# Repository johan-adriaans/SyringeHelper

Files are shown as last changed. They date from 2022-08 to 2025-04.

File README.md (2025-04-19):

# SyringeHelper
A 3D printable tool for repeatable precise dosing of insulin.

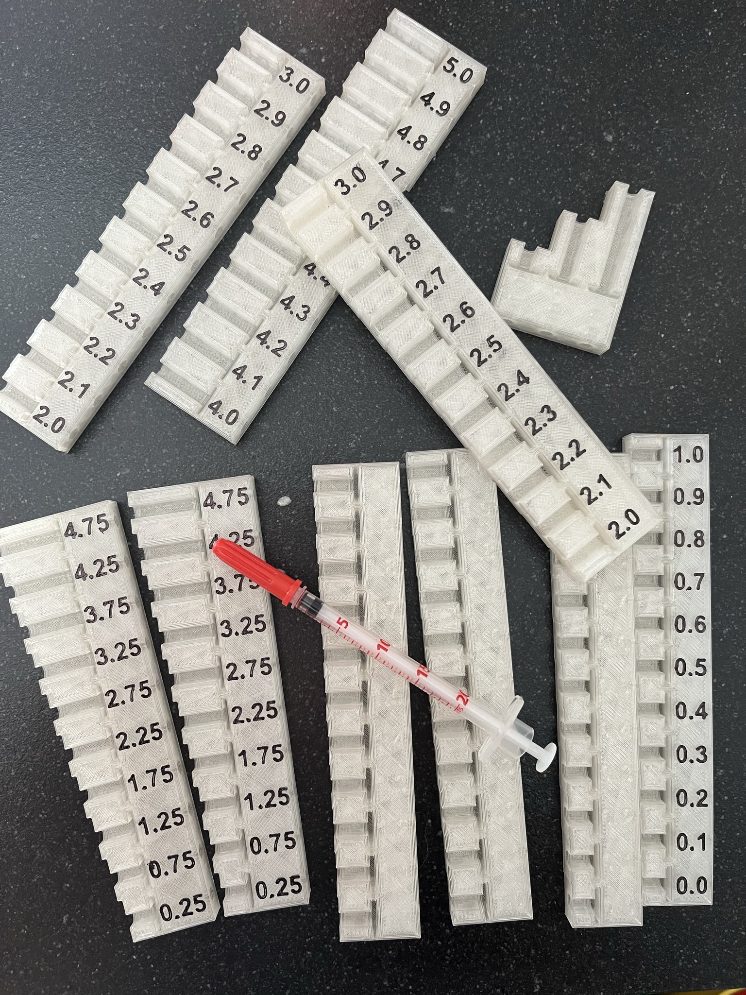
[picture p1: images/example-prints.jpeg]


Also published on:
- https://www.printables.com/model/253310-syringe-dosage-helper
- https://www.thingiverse.com/thing:5448298

## What is it
This is a tool that you fit around the syringe plunger head to get a precise dosage of insulin.

## Currently supported syringes
- BD Micro-Fine+ 0,5ml U40 8mm - EAN: [0382904876036](https://duckduckgo.com/?q=0382904876036)
- BD Micro-Fine+ Demi 0,3ml U100 8mm 30G - EAN: [0382904826031](https://duckduckgo.com/?q=0382904826031)
- BD Ultra-Fine 0,3ml U100 12,7mm 29G - EAN: [0382903261031](https://duckduckgo.com/?q=0382903261031) (Added by [Tony B](https://github.com/tony-butchart))
- Braun Omnican 20 0,5ml U40 8mm - EAN: [4039239541936](https://duckduckgo.com/?q=4039239541936)
- Sol-Vet U100 0,3ml 30G x 1/2" (0.3mm x 12,5mm) - GTIN: [0818392013016](https://www.gs1.org/services/verified-by-gs1/results?gtin=0818392013016)
- Sol-Vet U40 0,3ml 30G x 1/2" (0.3mm x 12,5mm) - REF: V3305-40 GTIN: [818392012682](https://www.gs1.org/services/verified-by-gs1/results?gtin=818392012682)
- Insumed U100 0,3ml 31G x 8mm - Rev. 01/2019 REF: 02 022725 030 150 - EAN: [08058090005322](https://duckduckgo.com/?q=Insumed+08058090005322)

A syringe type is nothing more than a set of values in an OpenSCAD include. It is very doable to add a new type. The code should speak for itself, but feel free to contact me if you have questions.

Note that the U-100 version currently centers on the top part of the plunger. This is a design choice made by https://www.diabetes-katzen.net in their excellent [paper version](https://www.diabetes-katzen.net/images/insulinspritzenmass/Insulinspritzenmass_mit_Erkl%c3%a4rung.pdf). Because we were initially using that, we kept the 0,1 unit offset.

## How to use
- First fill your syringe with a larger amount of insulin.
- Make sure all the bubbles are out.
- Fit the tool around the plunger head.
- Push the tool against the syringe body.
- Validate your result. If your result is different, check if the printed index has an offset. You can see this at the 0 point.

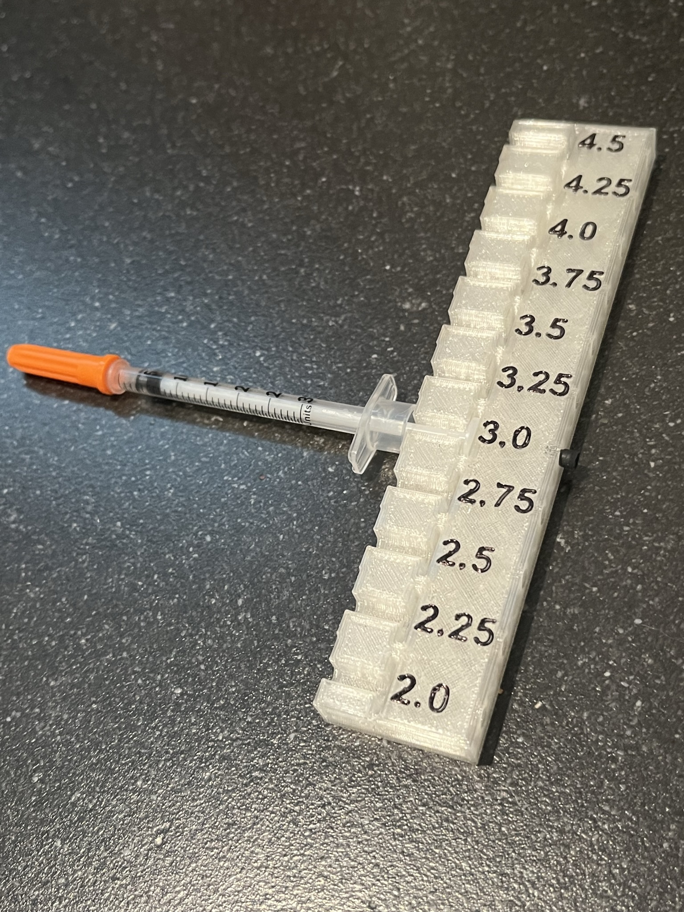
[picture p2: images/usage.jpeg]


Extra: The model has holes on the side where you can fit the rubber head of the plunger. Use this to mark your current dosage.

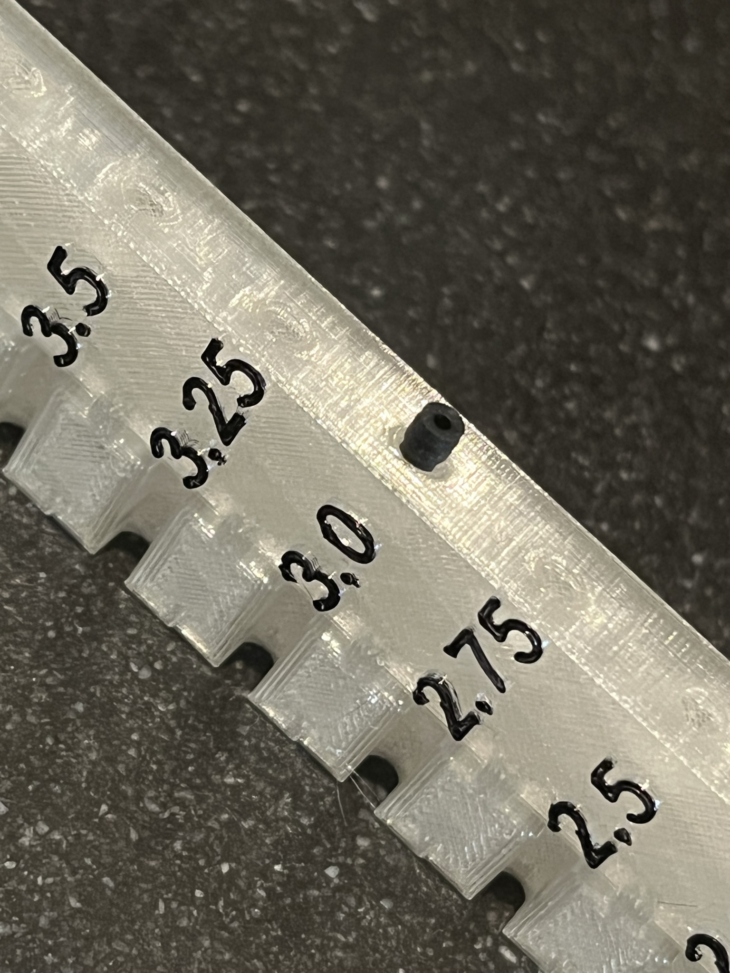
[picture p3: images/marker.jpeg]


## Create your own
You can download these files and open the SyringeHelper.scad file in OpenScad (you need the includes folder too). [OpenScad](https://openscad.org/) is free software that allows you to make a 3D model by programming. It might be a bit daunting to start with, but if you use a supported syringe, it boils down to changing 3 or 4 variables.

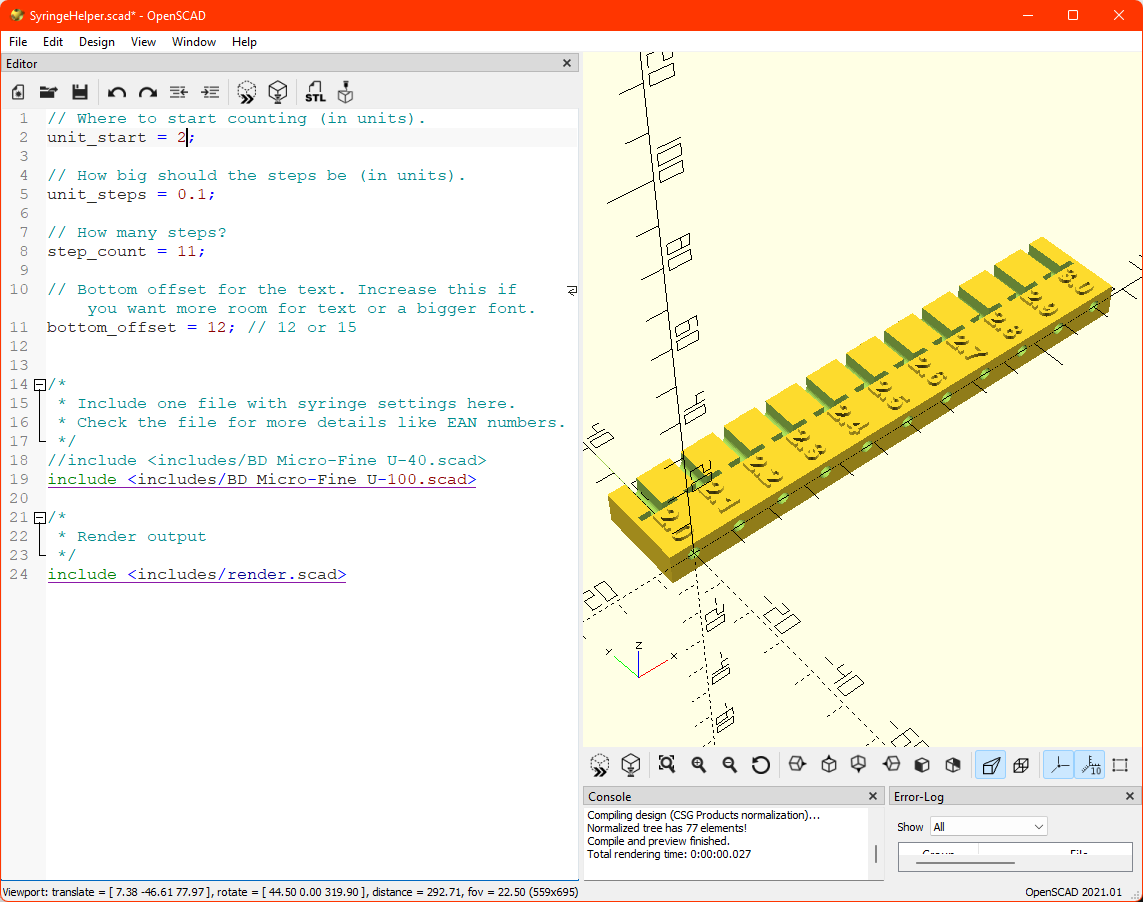
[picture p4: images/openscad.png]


## How did you calibrate?
We started by just measuring the index size of a full syringe. So for a syringe for 30 units of insulin, we would measure the distance between 0 and 30 units in millimeters and use that to calculate a ratio. After that we did some test prints with 3 steps of 10 units to fine-tune this ratio. We went a bit overboard and bought a precision balance ([Kern pcb 250-3](https://www.kern-sohn.com/cgi-bin/cosmoshop/lshop.cgi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)) to measure our results. This scale can repeatably measure down to 1 microgram, so we filled our syringes with water and we were able to ensure our results were correct and repeatable. We discovered the plastic part of the syringe is dependable enough to use as a measurement support. Luckily only the printed index is imprecise.

## Disclaimer
Please test your print before using. This was all calibrated for my 3D Printer (Creality Ender 3 V2). Do not assume my measurements are correct for your syringes. Test them on at least 10 syringes and decide for yourself if you feel comfortable using them.

## Background
We have a cat that needs insulin. A cat is a lot smaller than a human and needs more precise dosing. The pens we found would only be configurable for half a unit of insulin, while an animal as small as a cat could need changes down to 0.1 units. We also found that most manual syringes have a reasonably dependable plastic mold, but imprecise printing. The printed index on the syringe could differ up to 0.2 units. Long story short, it is impossible to measure a repeatable, precise dose without some sort of tool.. So we made a tool.

PS: If you have a diabetic cat and you speak Dutch, feel free to join the forum [Diabeteskatten.nl](https://www.diabeteskatten.nl) for expert advice and support.

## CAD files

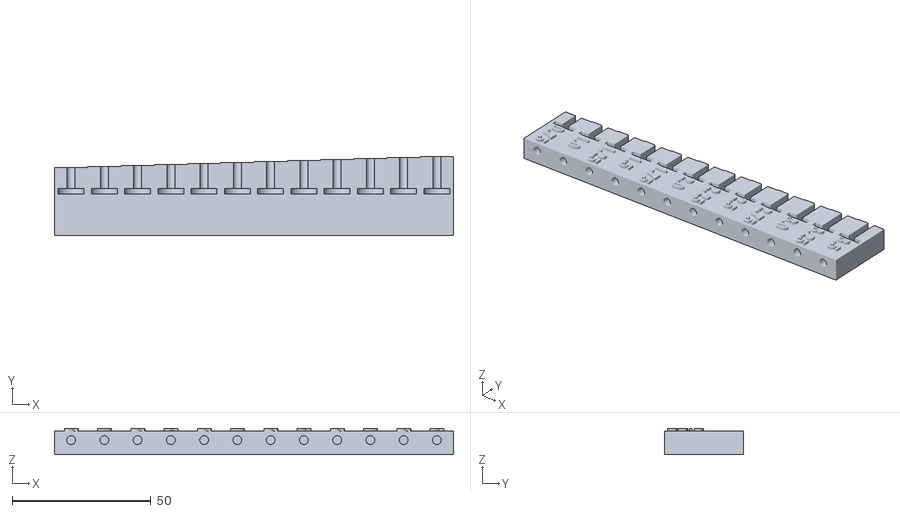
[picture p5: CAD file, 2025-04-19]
stl-examples/Insumed-U100-0.75-to-3.5.stl
144.0 x 28.4 x 9.40

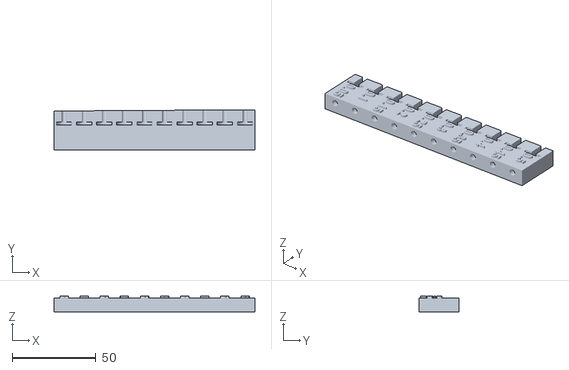
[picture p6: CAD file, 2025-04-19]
stl-examples/Insumed-U100-0.05-to-0.5.stl
120.0 x 24.1 x 9.40

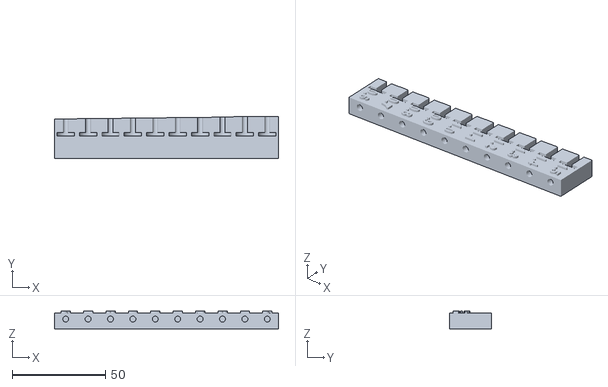
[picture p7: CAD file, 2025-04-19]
stl-examples/Insumed-U100-0.6-to-1.5.stl
120.0 x 22.6 x 9.40

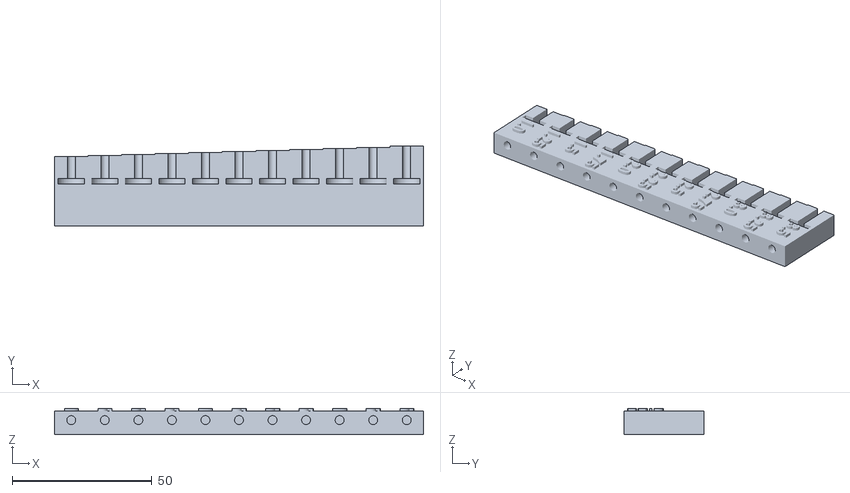
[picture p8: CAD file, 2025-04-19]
stl-examples/Insumed-U100-1-to-3.5.stl
132.0 x 28.4 x 9.40

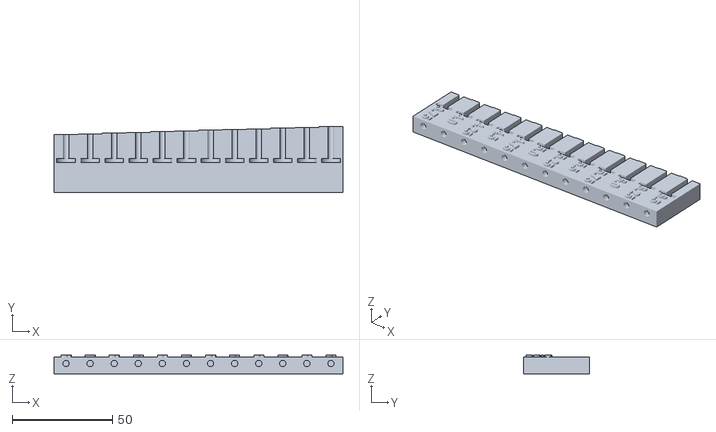
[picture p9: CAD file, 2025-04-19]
stl-examples/Insumed-U100-3.75-to-6.5.stl
144.0 x 32.8 x 9.40

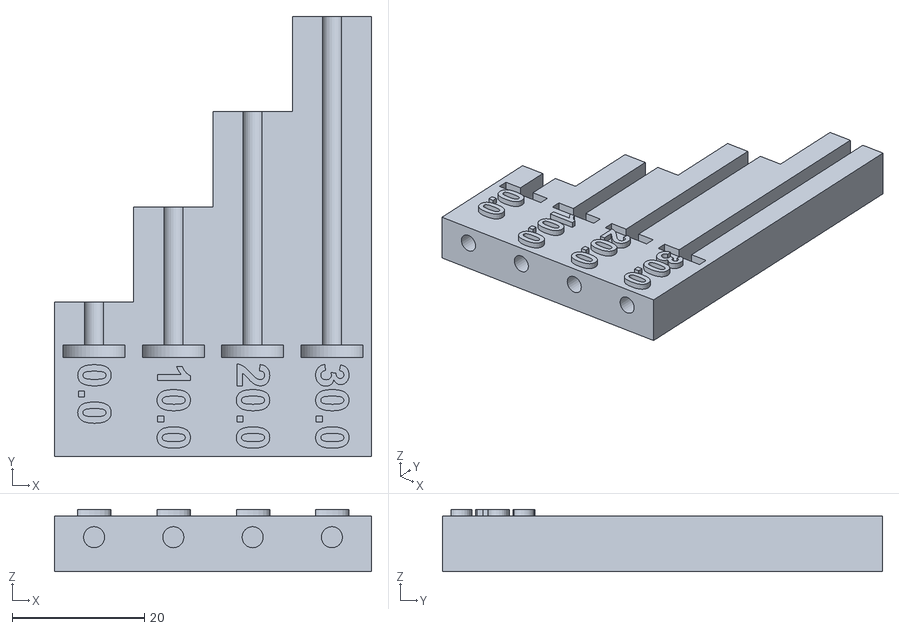
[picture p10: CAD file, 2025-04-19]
stl-examples/Insumed-U100-calibration.stl
48.0 x 66.6 x 9.40

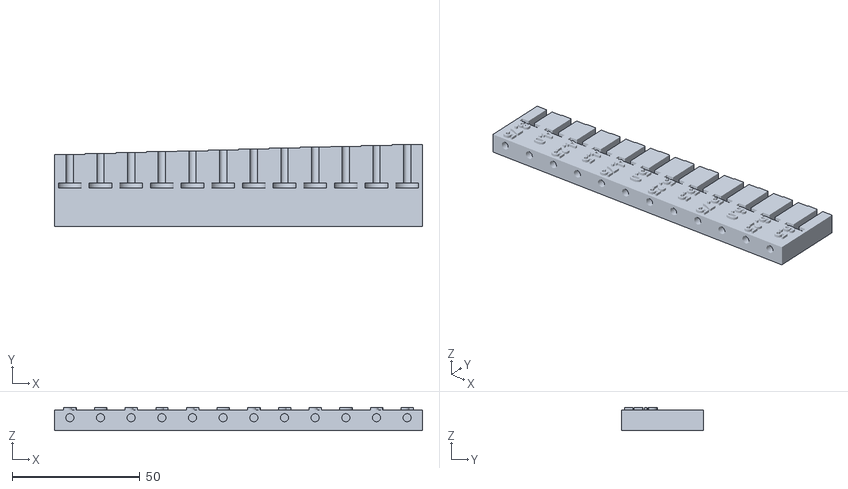
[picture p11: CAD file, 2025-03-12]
stl-examples/SolVet-U100-3.75-to-6.5.stl.stl
144.0 x 32.0 x 9.00

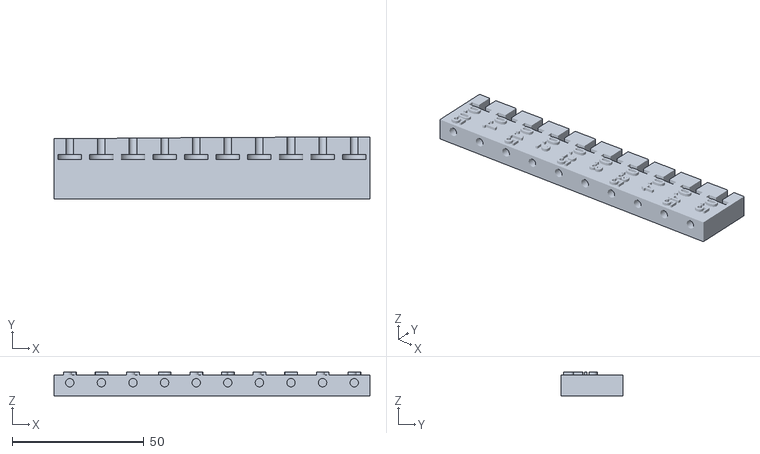
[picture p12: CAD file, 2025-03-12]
stl-examples/SolVet-U100-0.05-to-0.5.stl
120.0 x 23.7 x 9.00

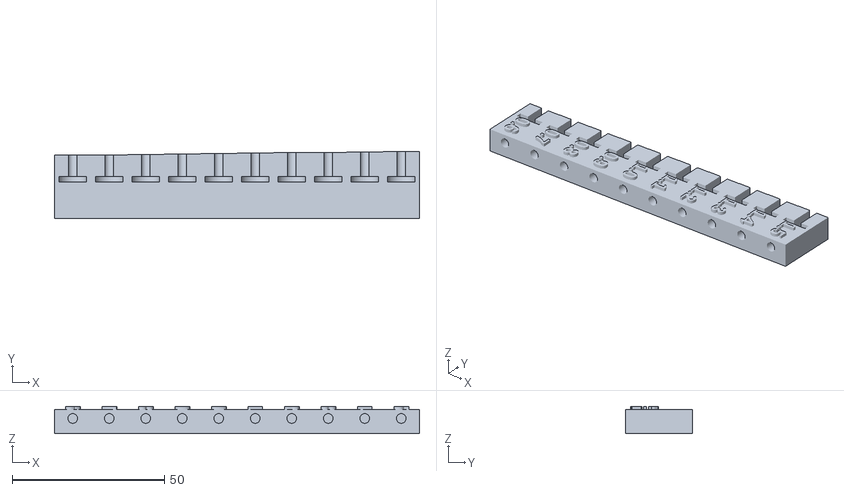
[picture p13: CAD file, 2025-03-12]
stl-examples/SolVet-U100-0.6-to-1.5.stl.stl
120.0 x 22.1 x 9.00

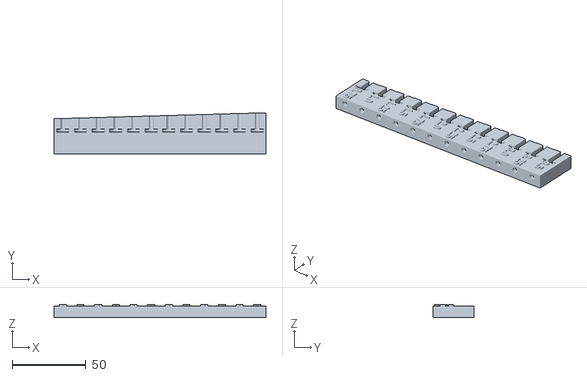
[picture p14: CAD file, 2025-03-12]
stl-examples/SolVet-U100-0.75-to-3.5.stl.stl
144.0 x 27.9 x 9.00

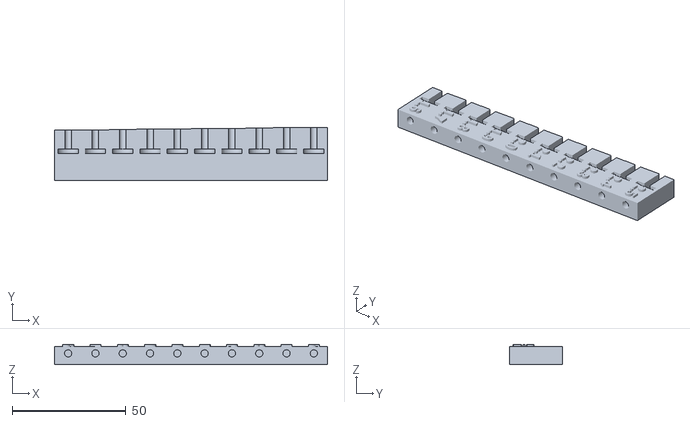
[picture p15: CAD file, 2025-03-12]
stl-examples/SolVet-U100-1.6-to-2.5.stl.stl
120.0 x 23.5 x 9.00

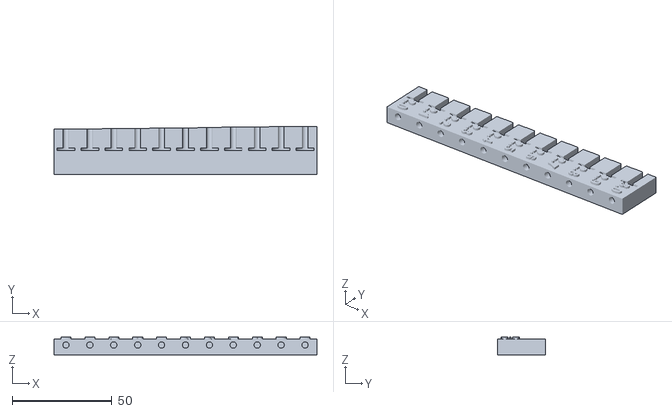
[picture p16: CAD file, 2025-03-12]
stl-examples/BDUltraFine-U100-2-to-3.stl
132.0 x 24.2 x 9.00

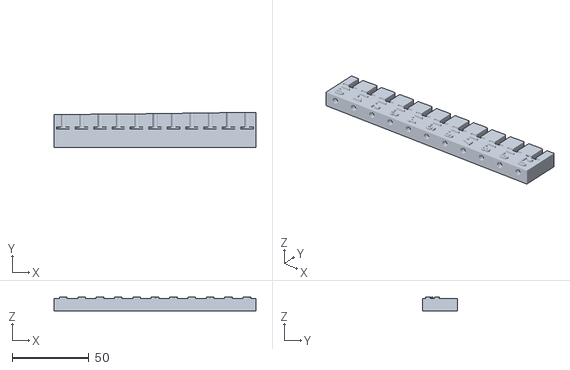
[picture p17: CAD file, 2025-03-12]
stl-examples/BDUltraFine-U100-1-to-2.stl
132.0 x 22.8 x 9.00

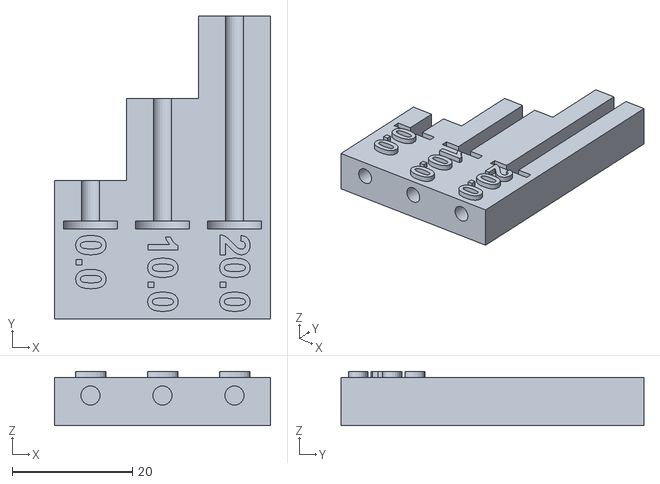
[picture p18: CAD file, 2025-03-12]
stl-examples/BDUltraFine-U100-calibration.stl
36.0 x 50.5 x 9.00

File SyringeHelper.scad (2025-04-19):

// Where to start counting (in units).
unit_start = 0;

// How big should the steps be (in units).
unit_steps = 0.1;

// How many steps?
step_count = 10;

// Bottom offset for the text. Increase this if you want more room for text or a bigger font.
bottom_offset = 12; // 12 or 15

/*
 * Include one file with syringe settings here.
 * Check the file for more details like EAN numbers.
 */
include <includes/Insumed U-100.scad>
//include <includes/Sol-Vet U-40.scad>
//include <includes/Sol-Vet U-100.scad>
//include <includes/Braun Omnican 20 U-40.scad>
//include <includes/BD Micro-Fine U-40.scad>
//include <includes/BD Micro-Fine U-100.scad>
//include <includes/BD Ultra-Fine U-100.scad>

/*
 * Render output 
 */
include <includes/render.scad>

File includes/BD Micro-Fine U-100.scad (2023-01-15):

/*
 * Values for:
 * BD Micro-Fine+ Demi 0,3ml U100 8mm 30G
 * EAN: 0382904826031
 */

// The ration between mm and units. Measure how many milimeter 1 unit is on your syringe.
unit_ratio = 41/30;

// Height of the gap for the plunger head (the part you hold when you push/pull).
plunger_head_gap_height = 1.5;

// Radius of the plunger head.
plunger_head_radius = 4.75;

// This is the gap between the tube and the bottom of the plunger head when the plunger is at 0.
plunger_head_offset = (7 - 0.1 * unit_ratio) + 1.4;

// In most syringes there is an gap between the zero marking and the actual zero.
// We have chosen to include this so it lines out with most syringe markings.
// This is optional as far as I am concerned. Set this to 0 if you want actual units.
real_zero_offset = 0;

// The radius of the plunger bar.
plunger_bar_radius = 1.5;

// Rubber piston marker radius.
rubber_piston_radius = 1.6;

// Rubber piston marker depth.
rubber_piston_depth = 4;

// The width of each block.
block_width = 12;

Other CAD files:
stl-examples/Insumed-U100-1.6-to-2.5.stl
stl-examples/BDUltraFine-U100-0-to-1.stl
stl-examples/BDUltraFine-U100-3-to-4.stl
stl-examples/SolVet-U40-1.6-to-2.5.stl
includes/BD Micro-Fine U-40.scad
includes/BD Ultra-Fine U-100.scad
includes/Braun Omnican 20 U-40.scad
includes/Insumed U-100.scad
includes/Sol-Vet U-100.scad
includes/Sol-Vet U-40.scad
includes/render.scad
stl-examples/BDMicroFine-U100-0-to-1.stl
stl-examples/BDMicroFine-U100-1-to-2.stl
stl-examples/BDMicroFine-U100-2-to-3.stl
stl-examples/BDMicroFine-U100-3-to-4.stl
stl-examples/BDMicroFine-U100-4-to-5.stl
stl-examples/BDMicroFine-U100-5-to-6.stl
stl-examples/BDMicroFine-U100-6-to-7.stl
stl-examples/BDMicroFine-U100-7-to-8.stl
stl-examples/BDMicroFine-U100-8-to-9.stl
stl-examples/BDMicroFine-U100-calibration.stl
stl-examples/BDMicroFine-U40-0-to-1.stl
stl-examples/BDMicroFine-U40-1-to-2.stl
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

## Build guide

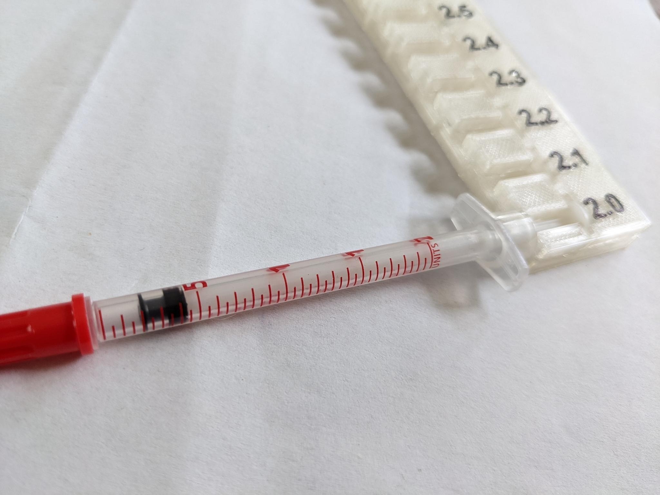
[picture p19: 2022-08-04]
images/usage2.jpg

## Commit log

2022-08-04 Added some example STL files and images
    [BDMicroFine-U100-0-to-1.stl, BDMicroFine-U100-1-to-2.stl, BDMicroFine-U100-2-to-3.stl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]
2023-01-15 Added BD Omnican 20 U40 syringe, tweaked some values so changing plunger head gap height does not influence body height.
    [BD Micro-Fine U-100.scad, BD Omnican 20 U-40.scad, SyringeHelper.scad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]
2023-01-15 Added some more sizes, re-rendered all stl files to add slightly bigger plunger head gap
    [BDMicroFine-U100-0-to-1.stl, BDMicroFine-U100-1-to-2.stl, BDMicroFine-U100-2-to-3.stl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]
2023-02-12 Update BD Omnican 20 U-40.scad
    [BD Omnican 20 U-40.scad]
2023-02-12 Rename BD Omnican 20 U-40.scad to Braun Omnican 20 U-40.scad
    [Braun Omnican 20 U-40.scad]
2024-05-23 Calibrated and added Sol-Vet U100 syringes
    [Sol-Vet U-100.scad, SolVet-U100-0-to-1.stl, SolVet-U100-1-to-2.stl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]
2024-05-23 Added 2 Sol-Vet examples witn 0.25 sized steps
    [SolVet-U100-1-to-3.5.stl, SolVet-U100-3.75-to-6.stl]
2024-09-01 Added SolVet U40 Syringe
    [Sol-Vet U-40.scad, SolVet-U40-0.05-to-0.5.stl, SolVet-U40-0.6-to-1.5.stl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]
2025-02-22 Include syringe data file for BD Ultra-Fine U-100
    Introduce data file for BD Ultra-Fine U-100 (EAN: 0382903261031) syringes which are commonly used for administering insulin in pets in Australia. Values were obtained by a combined average measuremen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
    [BD Ultra-Fine U-100.scad, SyringeHelper.scad]
2025-02-23 Update BD-UF-U100 unit_ratio and include STL examples
    [BD Ultra-Fine U-100.scad, BDUltraFine-U100-0-to-1.stl, BDUltraFine-U100-1-to-2.stl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]
2025-03-12 Added extra range of Solvet-U100 STL examples
    [SolVet-U100-0.05-to-0.5.stl, SolVet-U100-0.6-to-1.5.stl.stl, SolVet-U100-0.75-to-3.5.stl.stl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]
2025-04-19 Added Insumed U-100 syringe parameters
    [Insumed U-100.scad]
2025-04-19 Added Insumed U100 STL Examples
    [Insumed-U100-0.05-to-0.5.stl, Insumed-U100-0.6-to-1.5.stl, Insumed-U100-0.75-to-3.5.stl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]
